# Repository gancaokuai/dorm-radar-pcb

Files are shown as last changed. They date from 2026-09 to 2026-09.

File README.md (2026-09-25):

# Dorm Radar PCB

ESP32-C3 based local motion-alert PCB project. The system uses an LD2450 radar on the transmitter board and a local LED on the receiver board. Communication uses ESP-NOW. No camera, microphone, cloud service, or charging circuit is included.

## Boards

- TX board: 70 mm x 42 mm, LD2450 interface and ESP-NOW transmitter
- RX board: 68 mm x 42 mm, ESP-NOW receiver and LED indicator

## Hardware

- ESP32-C3-WROOM-02
- LD2450 24 GHz radar module
- MT3608 5 V boost converter
- AP2112K-3.3 regulator
- External protected 1S 18650 battery pack
- Two-layer PCB with bottom ground plane

## Repository Layout

```text
hardware/kicad/DormRadar/
  DormRadar.kicad_pro
  DormRadar.kicad_sch
  generate_schematic.py
  generate_pcbs.py
  release/
    BOM_common.csv
    BOM_TX.csv
    BOM_RX.csv
    TX/
      DormRadar_TX.kicad_pcb
      DRC.txt
      gerber/
      drill/
      position/
    RX/
      DormRadar_RX.kicad_pcb
      DRC.txt
      gerber/
      drill/
      position/
```

## Firmware

The initial ESP32-C3 firmware MVP is in `firmware/`.

- TX reads the LD2450 radar and sends detection state over ESP-NOW.
- RX validates the packet and drives the local LED.
- The build script uses `F:\DormRadar` as an ASCII junction because the ESP32 GCC toolchain cannot resolve the Chinese project path.
- Build with `F:\防宿管雷达\firmware\build.ps1 all`.

See `firmware/README.md` for pin mapping, thresholds, and first-board bring-up steps.
## Verification

- TX: 0 unconnected pads, 0 electrical errors
- RX: 0 unconnected pads, 0 electrical errors
- Remaining DRC items are silkscreen-only warnings caused by the ESP32 antenna overhang and local reference text placement.
- Freerouting 2.4.1 was used in single-thread mode, then all tracks below 0.20 mm were normalized to at least 0.20 mm.

## Notes

Use this design only in compliance with local rules and do not modify fire, access-control, or safety equipment. The radar should have direct line of sight to the intended detection zone.

## Licensing

This is a multi-licensed project. Firmware is under Apache-2.0, hardware design files are under CERN-OHL-W-2.0, and documentation is under CC BY-SA 4.0. See LICENSING.md and LICENSES/ for details.

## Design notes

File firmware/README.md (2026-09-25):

# 防宿管雷达固件 v0.1

这是项目的初步程序部分，目标是先打通最小闭环：

```text
LD2450 -> TX ESP32-C3 -> ESP-NOW -> RX ESP32-C3 -> LED
```

当前版本不包含摄像头、麦克风、云端、充电和联网服务。

## 目录

```text
firmware/
  arduino/tx/tx.ino                 TX 固件
  arduino/rx/rx.ino                 RX 固件
  lib/DormRadarConfig/              引脚和判定参数
  lib/DormRadarProtocol/            ESP-NOW 数据包格式与 CRC
  lib/Ld2450/                       LD2450 UART 流式解析器
  test/native/                      可选的电脑端单元测试
  build.ps1                         使用已安装 Arduino CLI 编译
```

## 当前行为

TX 端：

- 以 256000 baud 读取 LD2450。
- 连续解析 30 字节 LD2450 数据帧，支持串口数据分片。
- 从最多 3 个目标中选择最近目标。
- 默认检测区域为雷达前方 `x = -700..700 mm`、`y = 100..2500 mm`。
- 目标进入区域后立即触发，离开后保持 1500 ms。
- LD2450 坐标使用符号幅值编码，距离由 x/y 计算。
- 每 500 ms 至少发送一次 ESP-NOW；状态变化时立即发送。

RX 端：

- 校验协议版本、包类型和 CRC-8。
- 收到有效警报时点亮 LED。
- 1.8 秒收不到心跳时，以短闪方式提示无线链路丢失。
- 无警报时 LED 熄灭。

## 硬件引脚

| 功能 | ESP32-C3 GPIO |
| --- | ---: |
| LD2450 RX，接雷达 TX | GPIO5 |
| LD2450 TX，接雷达 RX | GPIO4 |
| RX LED 控制 | GPIO7 |
| UART0 TX/RX | GPIO21 / GPIO20 |
| BOOT | GPIO9 |
| EN | EN |

LED 电路为 3.3 V -> 电阻 -> LED 阳极，LED 阴极接 GPIO7，因此固件按低电平点亮处理。

## 编译

需要 Arduino CLI 和 `esp32:esp32` 开发板包。本机已缓存 ESP32 Arduino Core 2.0.14。

```powershell
cd F:\防宿管雷达\firmware
.\build.ps1 all
```

也可以分别编译：

```powershell
.\build.ps1 tx
.\build.ps1 rx
```

输出位于：

```text
firmware\.build\tx\
firmware\.build\rx\
```

## 烧录

1. 将 J3 编程口接到 USB-TTL 串口模块。
2. 使用 Arduino IDE 打开对应的 `tx.ino` 或 `rx.ino`。
3. 开发板选择 `ESP32C3 Dev Module`。
4. UART 下载时需要 GPIO8 上拉到 3.3 V、GPIO9 拉低；否则芯片会进入 USB_BOOT 模式。
5. 两块板必须使用同一个 ESP-NOW 信道，当前固定为信道 1。

## 调参

引脚、区域、触发时间和无线信道都在：

```text
firmware/lib/DormRadarConfig/src/BoardConfig.h
```

首板联调建议：

1. 先只运行 RX，用串口确认其正常启动。
2. 单独运行 TX，确认 LD2450 帧率约为 10 帧/秒。
3. 用实际人体目标记录 x/y，再调整区域边界。
4. 穿过一面墙测试 ESP-NOW 丢包和唤醒延迟。
5. 确认 LED 亮灭逻辑后，再进入低功耗和外壳装配优化。

## 重要说明

当前 LD2450 解析按常见公开帧格式实现：

```text
AA FF 03 00 + 3 * 8 字节目标数据 + 55 CC
```

正式接线前应以手上 LD2450 模块的实际固件说明为准，并先确认波特率、帧头、坐标符号和距离字段。若模块使用不同固件版本，应只修改 `lib/Ld2450`，不要改动无线协议和 RX 端。

ESP-NOW 初版使用广播，不加密。不要将它用于门禁、消防、安防报警或其他安全关键系统。

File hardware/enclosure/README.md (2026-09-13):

# Radar Device Enclosures

SolidWorks 2024 editable enclosure models for the TX and RX boards.

## TX Enclosure

- Outer dimensions: 77 mm x 61 mm x 24 mm
- PCB: 70 mm x 42 mm
- Four M2.5 mounting positions
- ESP32-C3 antenna opening
- Openings for battery, LD2450 and programming connectors

## RX Enclosure

- Outer dimensions: 75 mm x 61 mm x 24 mm
- PCB: 68 mm x 42 mm
- Four M2.5 mounting positions
- ESP32-C3 antenna opening
- Battery/programming cable openings
- 4 mm LED window

## Printing

- Material: PETG, ABS or PLA
- Layer height: 0.20 mm
- Perimeters: 3 to 4
- Infill: 20 to 30 percent
- Print the base with its floor on the build plate
- Print the cover flat
- Use M2.5 x 8 mm self-tapping screws, four per enclosure

The ESP32 antenna area must remain free of metal. Use a non-metallic enclosure only.

## Print Files

Each device folder contains:

- Base STL
- Cover STL
- Combined print-plate STL with base and cover pre-arranged
- SolidWorks SLDPRT/SLDASM source
- STEP exchange files

All STL files were verified as closed manifold meshes. The print plate files are ready to import directly into a slicer.

## Fastening

Recommended removable assembly, per device:

- 4 x M2.5 x 22 mm cross-head self-tapping screws
- 4 x M2.5 x 15 mm nylon through-spacers
- 4 x M2.5 nylon washers
- 4 x self-adhesive rubber feet

Alternative tape assembly:

- 4 x M2.5 x 5 mm self-tapping screws for the PCB-to-boss mounting
- 3M VHB or equivalent double-sided tape for the cover

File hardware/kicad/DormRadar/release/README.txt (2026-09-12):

防宿管雷达 PCB 发布说明
日期: 2026-09-12
KiCad: 10.0.6

板卡:
- TX: 70 mm x 42 mm, 包含 LD2450 接口和 ESP-NOW 发射端
- RX: 68 mm x 42 mm, 仅包含 ESP-NOW 接收端和 LED

设计要点:
- ESP32-C3-WROOM-02 天线区悬出板边，减少 PCB 尺寸并保持天线净空
- 1S 18650 电池输入，无充电功能
- MT3608 升压到 5V
- AP2112K-3.3 给 ESP32 供电
- 双层板，底层 GND 铺铜
- Freerouting 2.4.1 自动布线，单线程模式
- 最终 DRC: 0 个未连接焊盘，0 个电气错误，剩余仅为丝印边缘提示

生产文件:
- TX/gerber, TX/drill, TX/position
- RX/gerber, RX/drill, RX/position
- BOM_common.csv
- TX/DormRadar_TX.kicad_pcb
- RX/DormRadar_RX.kicad_pcb

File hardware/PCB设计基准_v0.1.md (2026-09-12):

# 防宿管雷达 PCB 设计基准 v0.1

## 1. 已确定约束
- 发射端和接收端使用 ESP-NOW。
- 无线链路距离约 2m，需要穿过一面墙。
- 雷达探测不需要穿墙。
- 红外对射方案取消。
- 接收端只需要 LED 提示。
- PCB 不设计充电功能。
- 电池允许使用多节 18650。
- 目标最低连续工作时间 24h。

## 2. 推荐系统形态
检测端：
LD2450 雷达 + ESP32-C3-MINI-1 + 1S3P 18650 + 5V 升压 + 3.3V LDO

接收端：
ESP32-C3-MINI-1 + LED + 1S2P 18650 + 5V 升压 + 3.3V LDO

建议做一块通用 PCB，通过元件不安装和固件选择实现两种版本：
- TX 版本：安装 LD2450 接口。
- RX 版本：不安装 LD2450，安装 LED。

## 3. 初步电路模块
1. 1S 锂电池输入
   - XT30 或 JST-VH 接口
   - 2A 保险丝或自恢复保险丝
   - 反接保护 P-MOSFET
   - TVS 和输入滤波电容
   - 不设计充电、均衡和电量计
2. 5V 升压
   - MT3608 作为初版方案
   - 5V 输出给 LD2450 和 3.3V LDO
   - 峰值输出能力按 0.8A 以上设计
3. 3.3V 电源
   - AP2112K-3.3 或同等级 600mA LDO
   - 给 ESP32-C3-MINI-1、LED 和调试接口供电
4. 主控
   - ESP32-C3-MINI-1，独立模块
   - EN 复位 RC、BOOT 上拉、去耦电容
   - 预留 TX/RX/EN/BOOT/GND/3.3V 调试焊盘或排针
5. 雷达接口
   - LD2450 5V、GND、TX、RX
   - 先按 3.3V UART 设计，正式布线前核对雷达数据手册
   - 雷达建议通过短排线外接，避免载体板地平面影响 24GHz 天线
6. LED
   - ESP32 GPIO 串 1k 电阻驱动单颗 LED
   - 低亮度版本不需要 MOSFET

## 4. PCB 初步指标
- 层数：2 层
- 板材：FR-4，1.6mm
- 铜厚：1oz
- 暂定尺寸：55mm x 30mm，不含外接电池组
- 电池组通过连接器外接，PCB 上不焊 18650 电池座
- 四角预留 M2.5 安装孔
- 雷达和 ESP32 天线分别布置在板两端

## 5. 布局要求
- ESP32-C3-MINI-1 天线端放在板边，天线投影区禁止铺铜和放金属件。
- 电池、电感、升压电路和雷达尽量远离 ESP32 天线。
- MT3608 的输入电容、电感、二极管和输出电容形成最小回路。
- 5V 和电池走线按至少 1A 设计，关键电源走线加宽并多打过孔。
- LD2450 若直接上板，其天线前方和下方必须按厂家说明保留净空。
- 雷达模块建议通过 5-pin 1.27mm 排线外接，便于调角度和减少遮挡。
- 接收端天线保持竖直，避免紧贴电池和金属外壳。

## 6. 电源估算
按 3 节 3500mAh 18650 并联：
- 标称能量约 38.9Wh。
- 可用能量按 80% 估算约 31Wh。
- 检测端平均功耗按 0.6-0.8W 估算。
- 预计续航约 39-52h。

按接收端 2 节 3500mAh 18650 并联：
- 标称能量约 25.9Wh。
- ESP32 持续接收场景预计可工作 50h 以上。
- LED 只在触发时点亮，对续航影响很小。

## 7. 后续必须确认
- 是否接受外接 18650 电池组，还是要求电池座集成到 PCB。
- PCB 最大允许尺寸和外壳安装方式。
- LD2450 使用外接排线还是直接贴装在 PCB 上。
- 编程方式使用 6-pin 排针、焊盘，还是增加仅用于数据编程的 USB-C。
- 墙面材质和 ESP-NOW 实测链路余量。

## 8. 计划交付物
- KiCad 原理图工程
- KiCad PCB 工程
- Gerber 和钻孔文件
- BOM 和贴片坐标文件
- 装配图
- 3D STEP 模型
- 打样和首板测试说明

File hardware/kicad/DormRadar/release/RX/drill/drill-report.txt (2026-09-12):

Drill report for DormRadar_RX.kicad_pcb
Created on 2026-09-12T20:41:57

Copper Layer Stackup:
    =============================================================
    L1 :  F.Cu                      front
    L2 :  B.Cu                      back

Drill file 'DormRadar_RX-PTH.drl' contains
    plated through holes:
    =============================================================
    T1  0.200mm  0.0079"  (12 holes))
    T2  0.300mm  0.0118"  (13 holes))
    T3  1.000mm  0.0394"  (5 holes))
    T4  1.700mm  0.0669"  (2 holes))

    Total plated holes count 32

Drill file 'DormRadar_RX-NPTH.drl' contains
    unplated through holes:
    =============================================================
    T1  2.700mm  0.1063"  (4 holes))

    Total unplated holes count 4

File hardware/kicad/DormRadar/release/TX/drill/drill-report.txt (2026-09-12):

Drill report for DormRadar_TX.kicad_pcb
Created on 2026-09-12T20:41:55

Copper Layer Stackup:
    =============================================================
    L1 :  F.Cu                      front
    L2 :  B.Cu                      back

Drill file 'DormRadar_TX-PTH.drl' contains
    plated through holes:
    =============================================================
    T1  0.200mm  0.0079"  (12 holes))
    T2  0.300mm  0.0118"  (15 holes))
    T3  0.650mm  0.0256"  (5 holes))
    T4  1.000mm  0.0394"  (5 holes))
    T5  1.700mm  0.0669"  (2 holes))

    Total plated holes count 39

Drill file 'DormRadar_TX-NPTH.drl' contains
    unplated through holes:
    =============================================================
    T1  2.700mm  0.1063"  (4 holes))

    Total unplated holes count 4

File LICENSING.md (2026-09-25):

# Licensing

This repository contains multiple categories of works with different licenses.

## Firmware

The firmware source code under `firmware/` is licensed under the Apache License 2.0.

SPDX-License-Identifier: Apache-2.0

Full text: `LICENSES/Apache-2.0.txt`

## Hardware Design

The hardware design files under `hardware/`, including KiCad schematics, PCB layouts, BOM files, manufacturing outputs, mechanical design files, and enclosure files, are licensed under the CERN Open Hardware Licence Version 2 - Weakly Reciprocal.

SPDX-License-Identifier: CERN-OHL-W-2.0

Full text: `LICENSES/CERN-OHL-W-2.0.txt`

## Documentation

Project documentation and explanatory text, including `README.md`, `firmware/README.md`, and other documentation files, are licensed under the Creative Commons Attribution-ShareAlike 4.0 International License.

SPDX-License-Identifier: CC-BY-SA-4.0

Full text: `LICENSES/CC-BY-SA-4.0.txt`

## Third-Party Material

Third-party libraries, components, datasheets, trademarks, and referenced materials remain subject to their respective licenses and terms. If a file contains an explicit license notice or SPDX identifier, that notice takes precedence for that file.

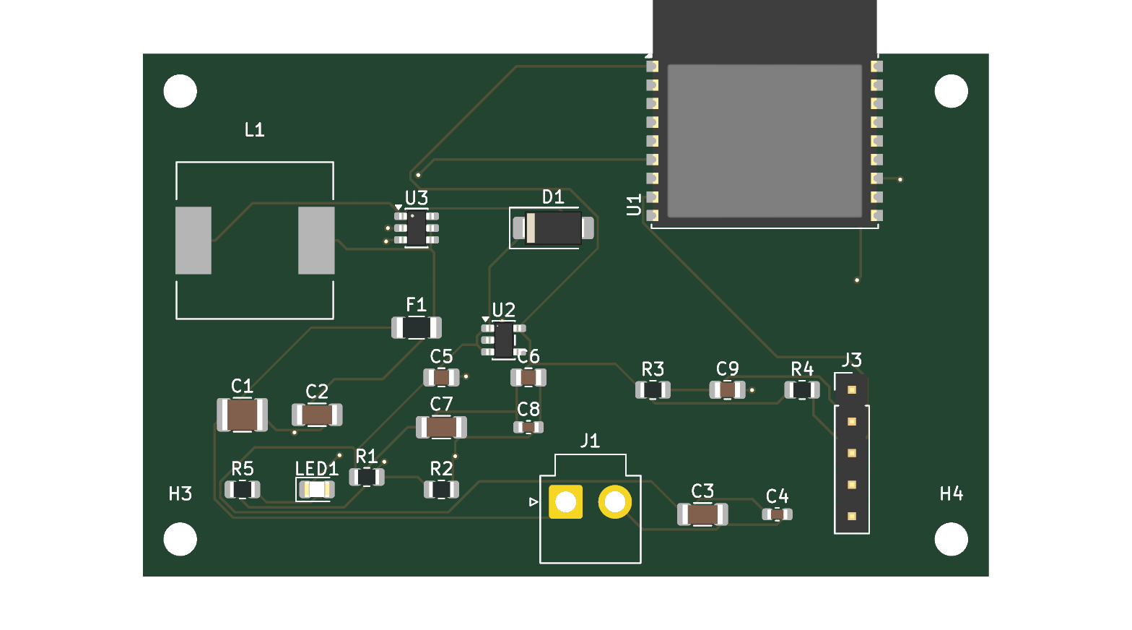
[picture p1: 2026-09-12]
hardware/kicad/DormRadar/release/RX/DormRadar_RX_final.png

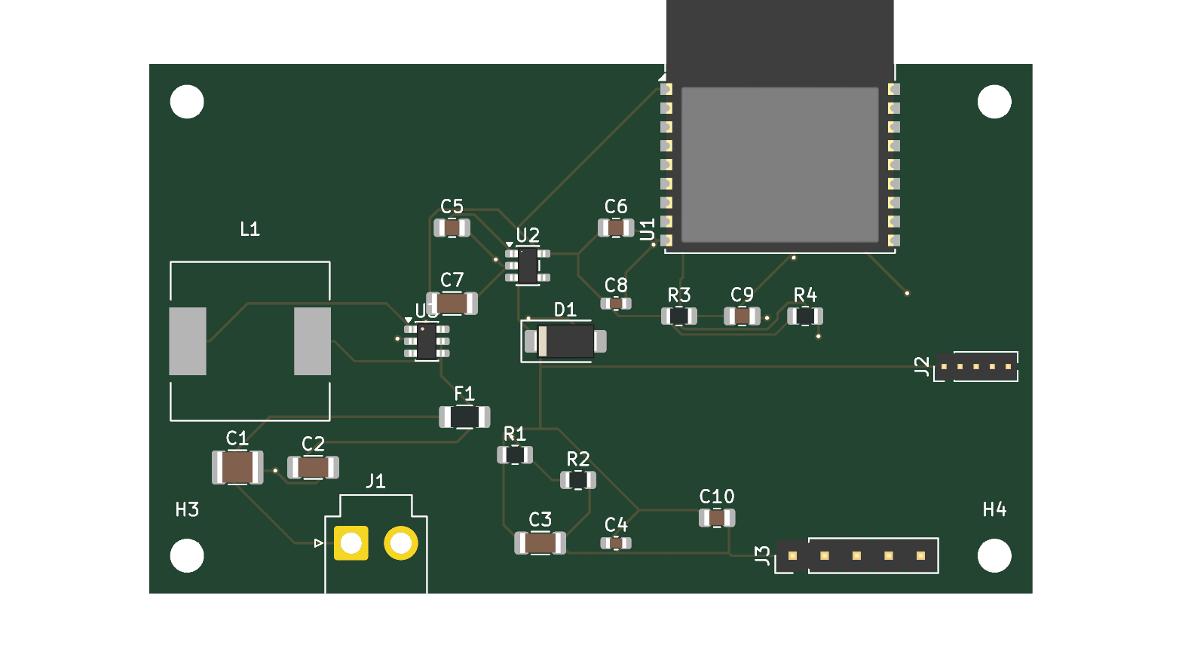
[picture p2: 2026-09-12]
hardware/kicad/DormRadar/release/TX/DormRadar_TX_final.png

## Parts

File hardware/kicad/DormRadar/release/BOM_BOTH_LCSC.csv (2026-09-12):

Comment | Designator | Footprint | Quantity | Supplier
100uF 10V X5R | TXC1,RXC1 | 1210 | 2 | C23742
22uF 25V X5R | TXC2,TXC3,RXC2,RXC3 | 1206 | 4 | C12891
0.1uF 50V X7R | TXC4,TXC8,RXC4,RXC8 | 0603 | 4 | C1591
1uF 50V X7R | TXC5,TXC6,TXC9,RXC5,RXC6,RXC9 | 0805 | 6 | C28323
22uF 6.3V X5R | TXC7,RXC7 | 1206 | 2 | C159759
10uF 25V X5R | TXC10 | 0805 | 1 | C15850
SS34 Schottky | TXD1,RXD1 | SMA | 2 | C8678
Fuse 2A 1206 | TXF1,RXF1 | 1206 | 2 | C3105
JST VH B2P-VH-B | TXJ1,RXJ1 | JST VH 2P 3.96mm | 2 | C265114
Header 1.27mm 1x5 | TXJ2 | 1.27mm 1x5 | 1 | C962329
Header 2.54mm 1x5 | TXJ3,RXJ3 | 2.54mm 1x5 | 2 | C492404
Inductor 22uH 3.6A | TXL1,RXL1 | 12.3x12.3mm | 2 | C9905
Resistor 73.2k 1% | TXR1,RXR1 | 0805 | 2 | C228988
Resistor 10k 1% | TXR2,TXR3,TXR4,RXR2,RXR3,RXR4 | 0805 | 6 | C84376
Resistor 470R 1% | RXR5 | 0805 | 1 | C114564
LED Red | RXLED1 | 0805 | 1 | C2295
ESP32-C3-WROOM-02-N4 | TXU1,RXU1 | SMD 20x18mm | 2 | C2934560
AP2112K-3.3TRG1 | TXU2,RXU2 | SOT-25-5 | 2 | C51118
MT3608 | TXU3,RXU3 | SOT-23-6 | 2 | C84817

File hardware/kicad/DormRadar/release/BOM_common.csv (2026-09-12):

Refs | Value | Footprint | Qty | DNP
C1 | 100uF/10V | Capacitor_SMD:C_1210_3225Metric | 1
C2 | 22uF/10V | Capacitor_SMD:C_1206_3216Metric | 1
C3 | 22uF/10V | Capacitor_SMD:C_1206_3216Metric | 1
C4 | 0.1uF | Capacitor_SMD:C_0603_1608Metric | 1
C5 | 1uF | Capacitor_SMD:C_0805_2012Metric | 1
C6 | 1uF | Capacitor_SMD:C_0805_2012Metric | 1
C7 | 22uF/6.3V | Capacitor_SMD:C_1206_3216Metric | 1
C8 | 0.1uF | Capacitor_SMD:C_0603_1608Metric | 1
C9 | 1uF | Capacitor_SMD:C_0805_2012Metric | 1
C10 | 10uF/10V | Capacitor_SMD:C_0805_2012Metric | 1
D1 | SS34 | Diode_SMD:D_SMA | 1
F1 | 2A | Fuse:Fuse_1206_3216Metric | 1
J1 | BAT_1S | Connector_JST:JST_VH_B2P-VH-B_1x02_P3.96mm_Vertical | 1
J2 | LD2450 | Connector_PinHeader_1.27mm:PinHeader_1x05_P1.27mm_Vertical | 1
J3 | PROG | Connector_PinHeader_2.54mm:PinHeader_1x05_P2.54mm_Vertical | 1
L1 | 22uH | Inductor_SMD:L_12x12mm_H4.5mm | 1
LED1 | RED | LED_SMD:LED_0805_2012Metric | 1
R1 | 73.2k | Resistor_SMD:R_0805_2012Metric | 1
R2 | 10k | Resistor_SMD:R_0805_2012Metric | 1
R3 | 10k | Resistor_SMD:R_0805_2012Metric | 1
R4 | 10k | Resistor_SMD:R_0805_2012Metric | 1
R5 | 470R | Resistor_SMD:R_0805_2012Metric | 1
U1 | ESP32-C3-WROOM-02 | RF_Module:ESP32-C3-WROOM-02 | 1
U2 | AP2112K-3.3 | Package_TO_SOT_SMD:SOT-23-5 | 1
U3 | MT3608 | Package_TO_SOT_SMD:SOT-23-6 | 1

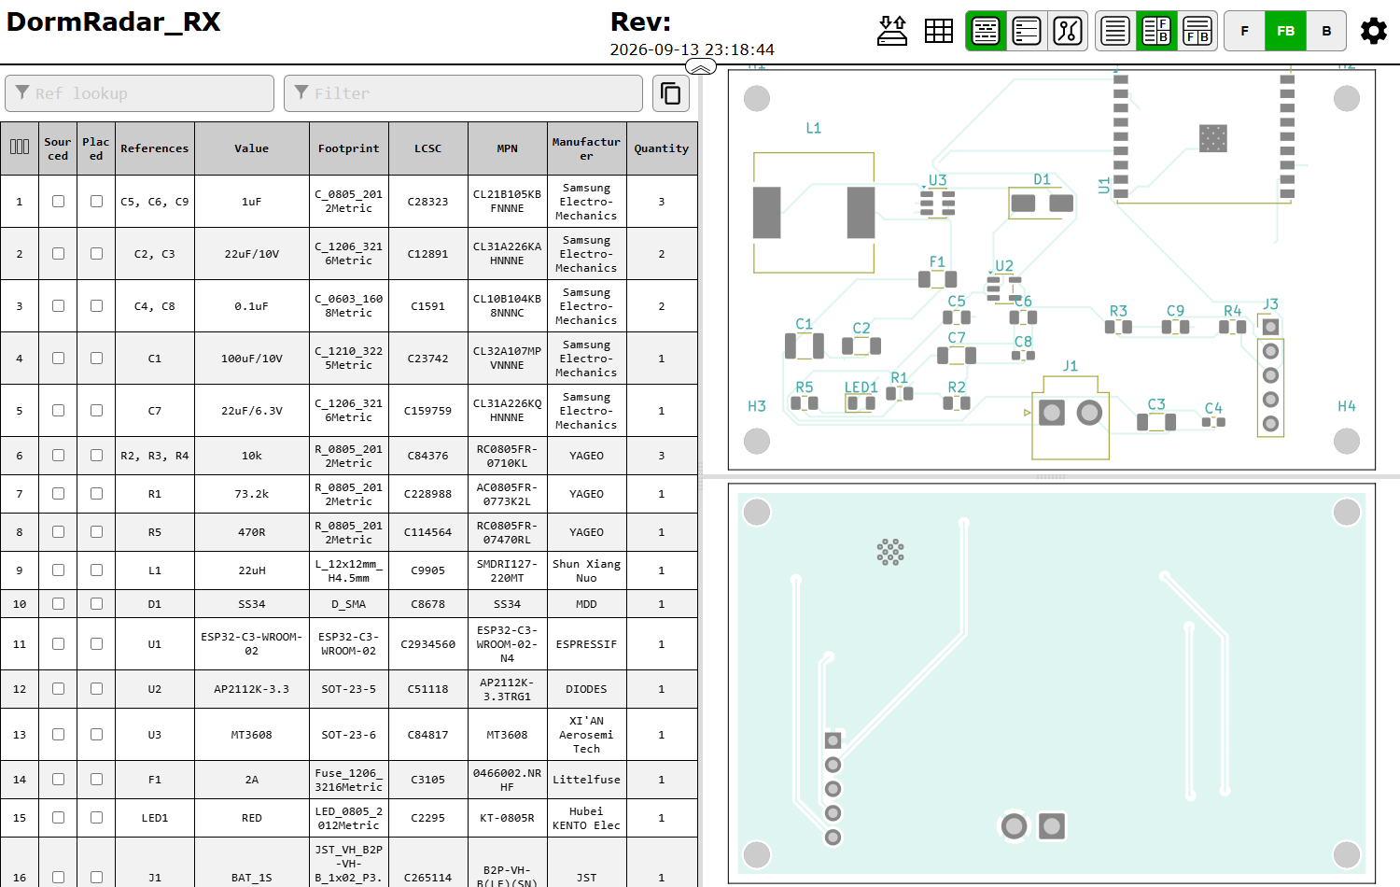
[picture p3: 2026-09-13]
hardware/kicad/DormRadar/release/RX/iBOM_RX_preview.png

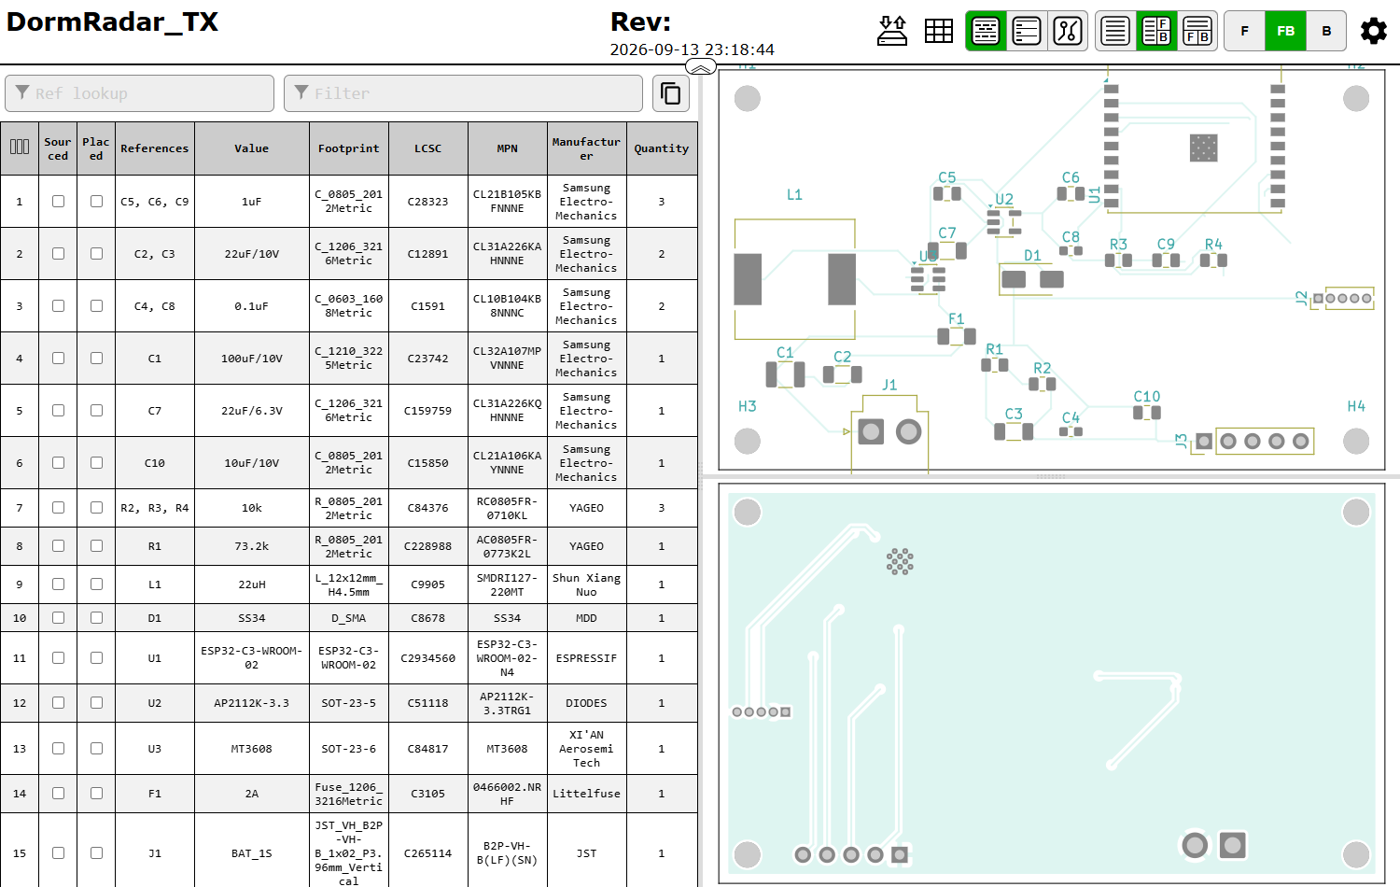
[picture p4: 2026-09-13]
hardware/kicad/DormRadar/release/TX/iBOM_TX_preview.png

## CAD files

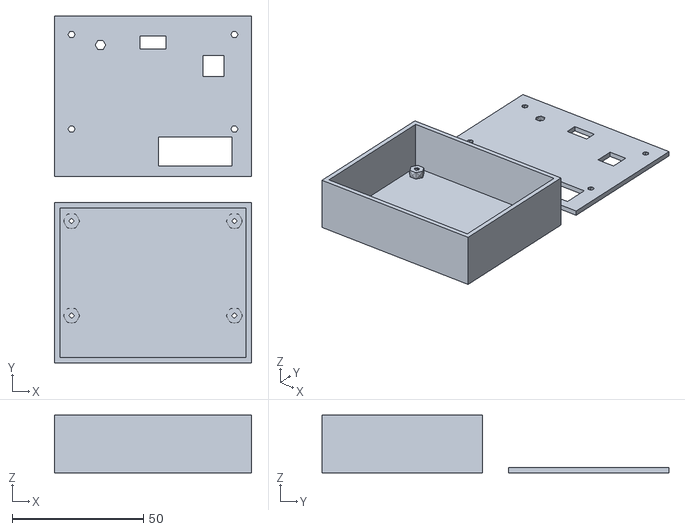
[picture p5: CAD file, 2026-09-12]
hardware/enclosure/RX/RX_PrintPlate.stl
75.0 x 132.0 x 22.0

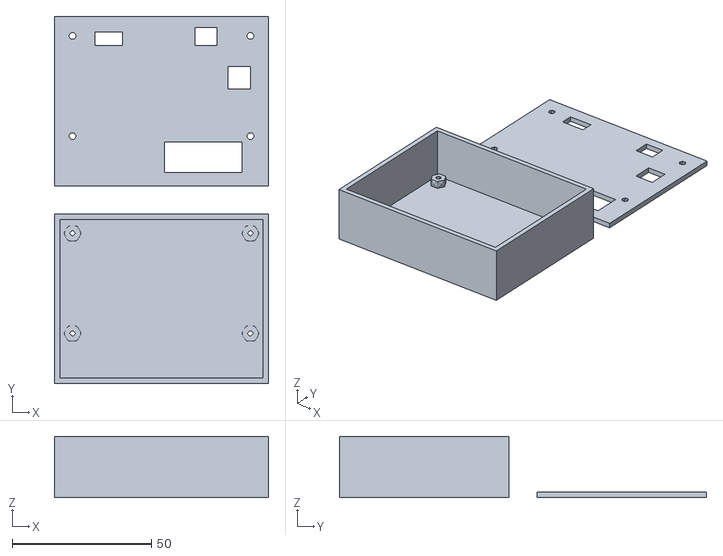
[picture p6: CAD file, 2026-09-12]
hardware/enclosure/TX/TX_PrintPlate.stl
77.0 x 132.0 x 22.0

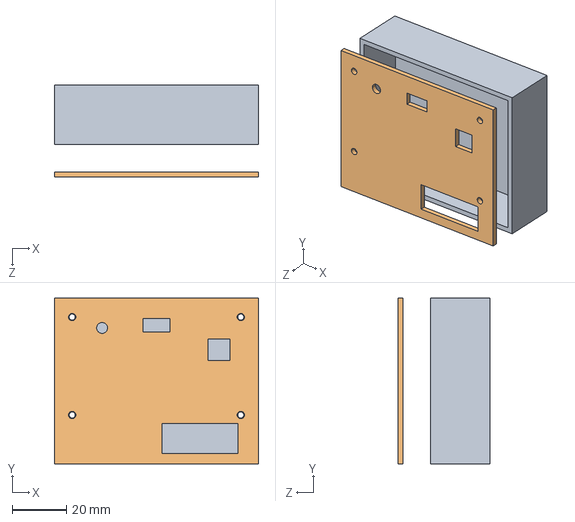
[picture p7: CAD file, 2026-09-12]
hardware/enclosure/RX/RX_Enclosure.STEP
75.0 x 61.0 x 34.0 mm
RX_Base
RX_Cover

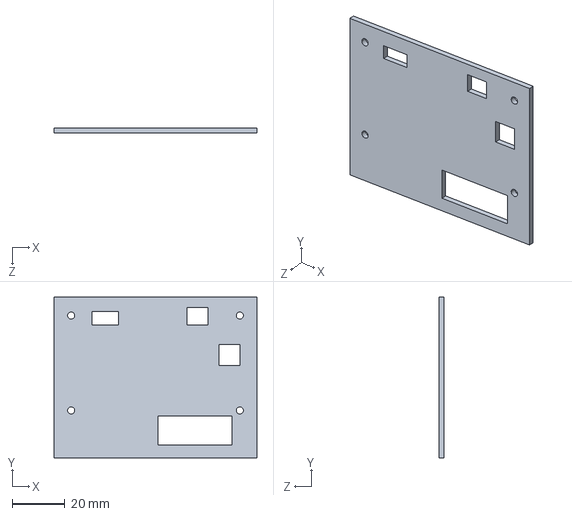
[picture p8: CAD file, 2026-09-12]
hardware/enclosure/TX/TX_Cover.STEP
77.0 x 61.0 x 2.00 mm

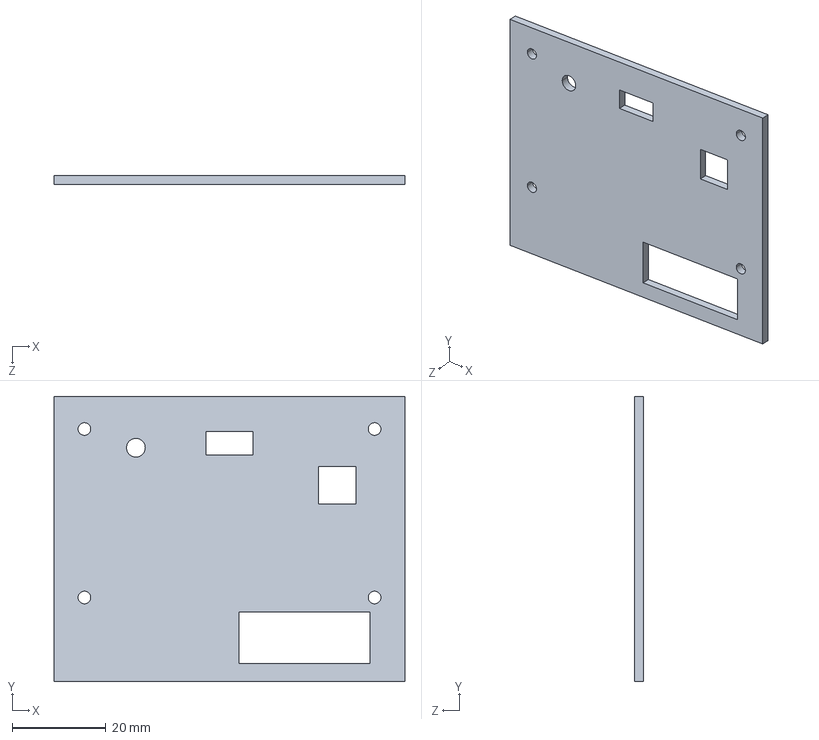
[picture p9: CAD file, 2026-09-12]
hardware/enclosure/RX/RX_Cover.STEP
75.0 x 61.0 x 2.00 mm

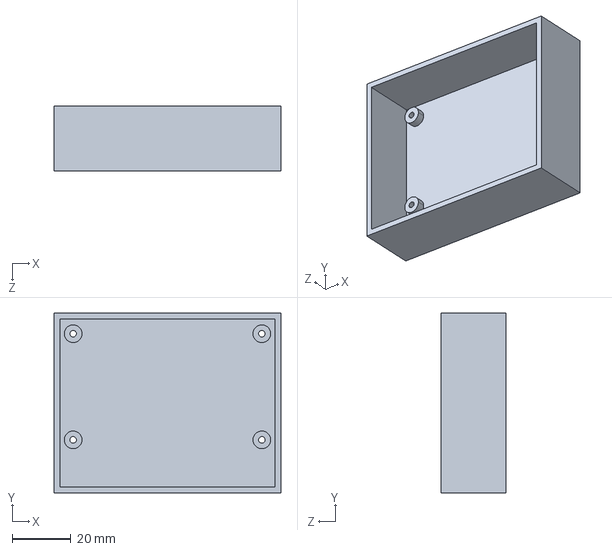
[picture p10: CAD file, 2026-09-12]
hardware/enclosure/TX/TX_Base.STEP
77.0 x 61.0 x 22.0 mm

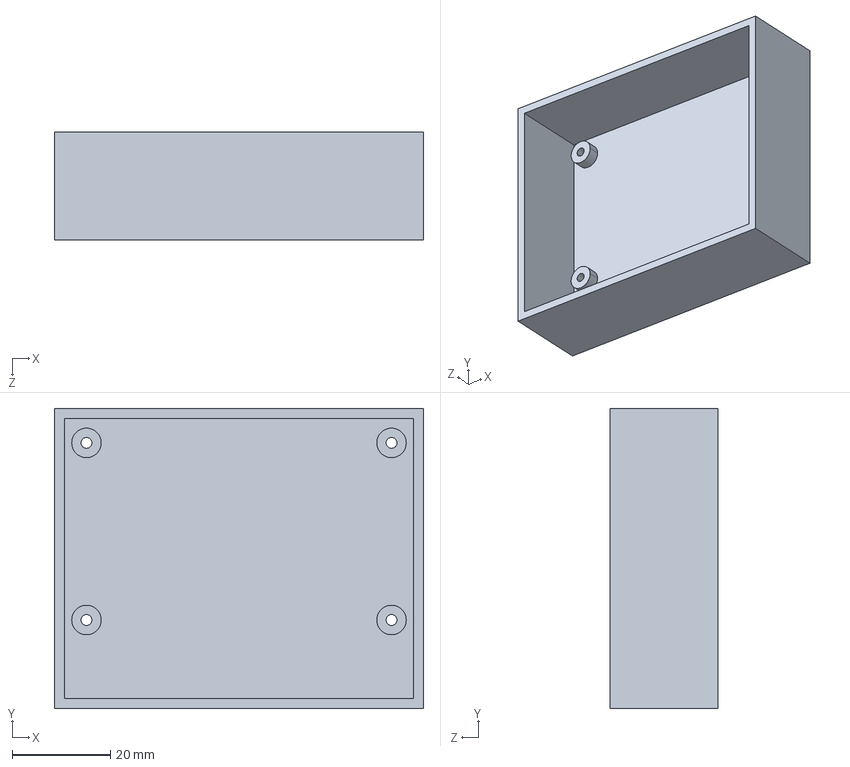
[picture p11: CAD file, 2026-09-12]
hardware/enclosure/RX/RX_Base.STEP
75.0 x 61.0 x 22.0 mm

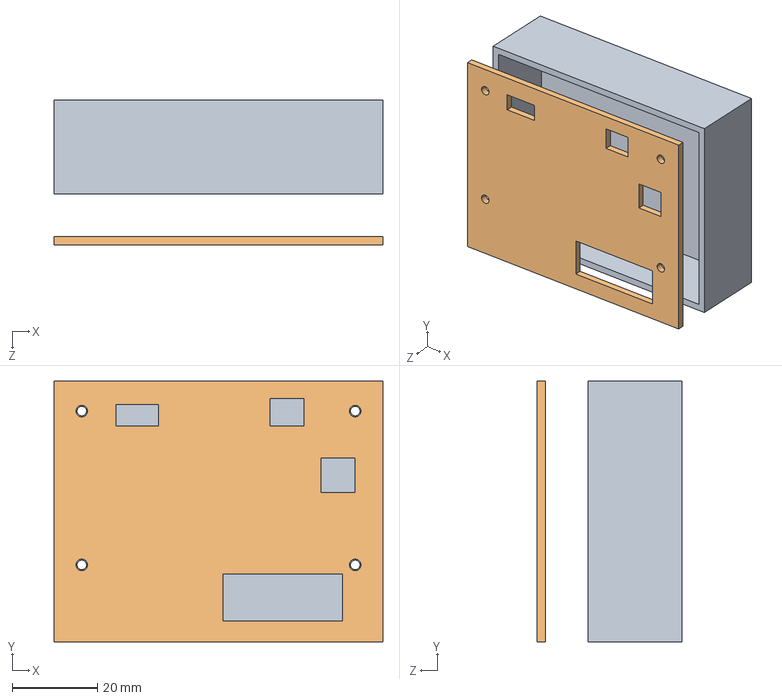
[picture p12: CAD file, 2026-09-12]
hardware/enclosure/TX/TX_Enclosure.STEP
77.0 x 61.0 x 34.0 mm
TX_Base
TX_Cover

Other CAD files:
hardware/enclosure/RX/RX_Base.SLDPRT
hardware/enclosure/RX/RX_Base.stl
hardware/enclosure/RX/RX_Cover.SLDPRT
hardware/enclosure/RX/RX_Cover.stl
hardware/enclosure/RX/RX_Enclosure.SLDASM
hardware/enclosure/TX/TX_Base.SLDPRT
hardware/enclosure/TX/TX_Base.stl
hardware/enclosure/TX/TX_Cover.SLDPRT
hardware/enclosure/TX/TX_Cover.stl
hardware/enclosure/TX/TX_Enclosure.SLDASM

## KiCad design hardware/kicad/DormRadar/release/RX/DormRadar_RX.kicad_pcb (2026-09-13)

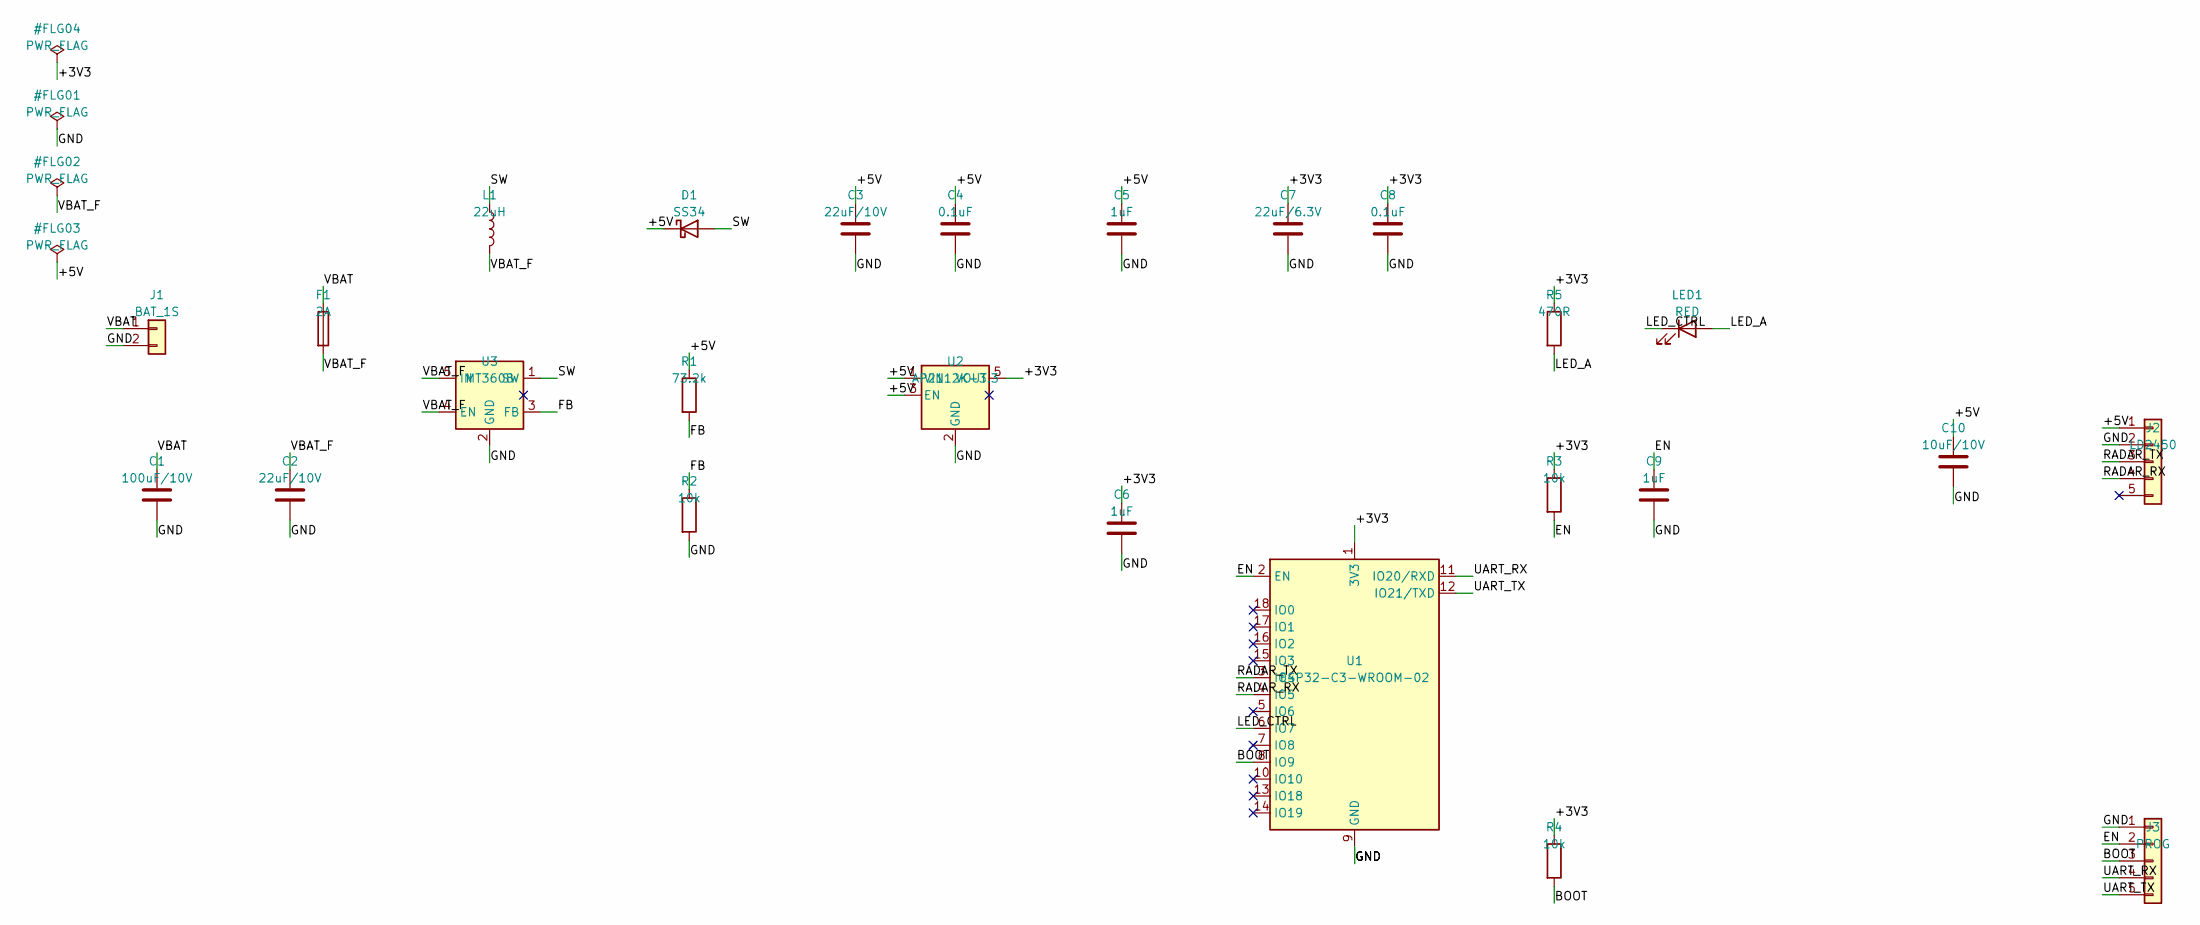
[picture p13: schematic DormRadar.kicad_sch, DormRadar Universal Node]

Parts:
C1: 100uF/10V; C_1210_3225Metric
C2, C3: 22uF/10V; C_1206_3216Metric
C4, C8: 0.1uF; C_0603_1608Metric
C5, C6, C9: 1uF; C_0805_2012Metric
C7: 22uF/6.3V; C_1206_3216Metric
C10: 10uF/10V; C_0805_2012Metric
D1: SS34; D_SMA
F1: 2A; Fuse_1206_3216Metric
J1: BAT_1S; JST_VH_B2P-VH-B_1x02_P3.96mm_Vertical
J2: LD2450; PinHeader_1x05_P1.27mm_Vertical
J3: PROG; PinHeader_1x05_P2.54mm_Vertical
L1: 22uH; L_12x12mm_H4.5mm
LED1: RED; LED_0805_2012Metric
R1: 73.2k; R_0805_2012Metric
R2, R3, R4: 10k; R_0805_2012Metric
R5: 470R; R_0805_2012Metric
U1: ESP32-C3-WROOM-02
U2: AP2112K-3.3; SOT-23-5
U3: MT3608; SOT-23-6

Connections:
+3V3: C6.1, C7.1, C8.1, R3.1, R4.1, R5.1, U1.1 (3V3), U2.5
+5V: C3.1, C4.1, C5.1, C10.1, D1.1 (K), J2.1, R1.1, U2.1, U2.3
BOOT: J3.3, R4.2, U1.8 (IO9)
EN: C9.1, J3.2, R3.2, U1.2 (EN)
FB: R1.2, R2.1, U3.3 (FB)
GND: C1.2, C2.2, C3.2, C4.2, C5.2, C6.2, C7.2, C8.2, C9.2, C10.2, J1.2, J2.2, J3.1, R2.2, U1.9 (GND), U1.19 (GND), U2.2, U3.2 (GND)
LED_A: LED1.2 (A), R5.2
LED_CTRL: LED1.1 (K), U1.6 (IO7)
RADAR_RX: J2.4, U1.4 (IO5)
RADAR_TX: J2.3, U1.3 (IO4)
SW: D1.2 (A), L1.1, U3.1 (SW)
UART_RX: J3.4, U1.11 (IO20/RXD)
UART_TX: J3.5, U1.12 (IO21/TXD)
VBAT: C1.1, F1.1, J1.1
VBAT_F: C2.1, F1.2, L1.2, U3.4 (EN), U3.5 (IN)

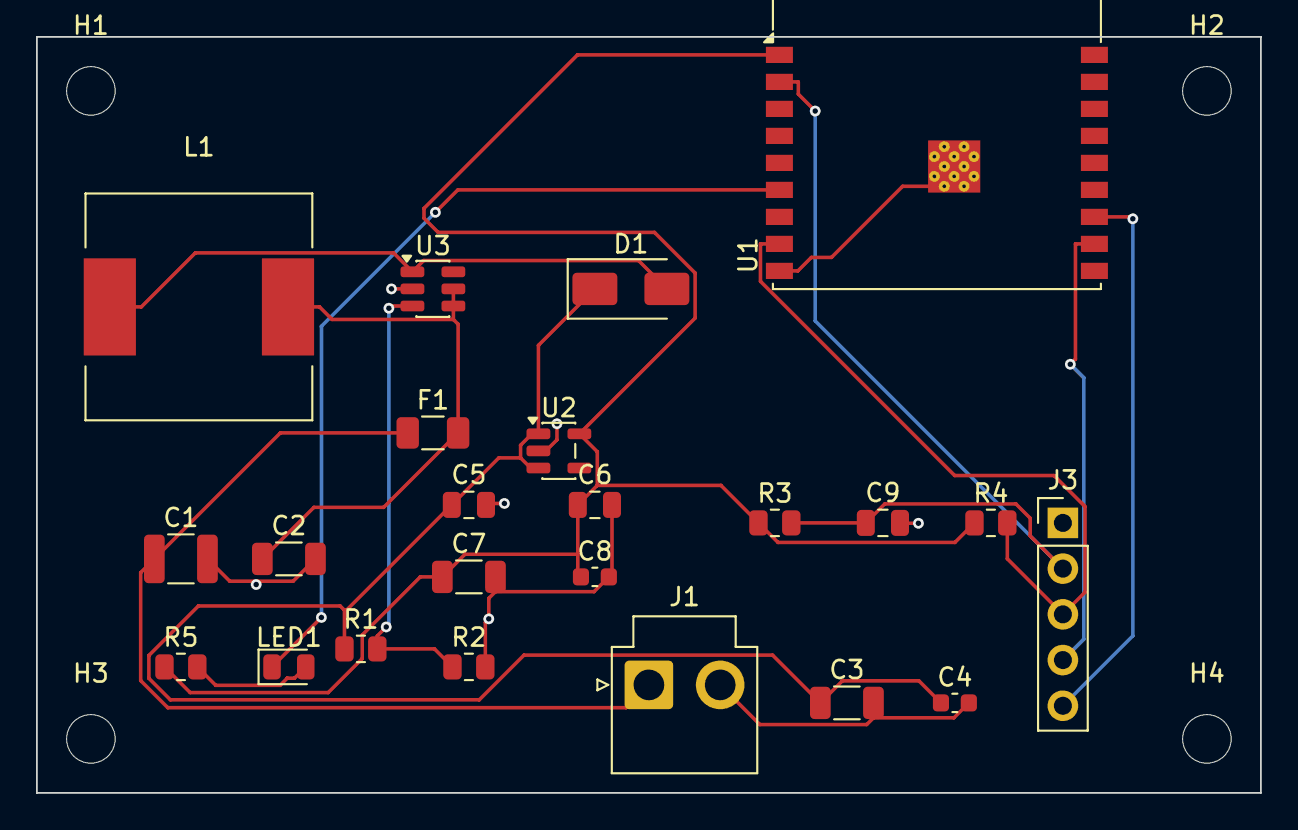
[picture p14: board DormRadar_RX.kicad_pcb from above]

Board: 2 copper layers, 68.0 x 42.0 mm, 27 parts (0 on the bottom side), 13 nets.

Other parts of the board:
H1, H2, H3, H4: M2.5; MountingHole_2.7mm_M2.5

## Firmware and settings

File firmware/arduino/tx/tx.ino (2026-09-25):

#include <Arduino.h>
#include "F:/DormRadar/firmware/lib/DormRadarConfig/src/BoardConfig.h"
#include "F:/DormRadar/firmware/lib/DormRadarProtocol/src/DormRadarProtocol.h"
#include "F:/DormRadar/firmware/lib/Ld2450/src/Ld2450.h"
#include <WiFi.h>
#include <esp_now.h>
#include <esp_wifi.h>

namespace cfg = dorm_radar::config;
using dorm_radar::DetectionPacket;
using dorm_radar::Ld2450Parser;
using dorm_radar::RadarFrame;
using dorm_radar::RadarTarget;

namespace {

HardwareSerial RadarSerial(1);
Ld2450Parser radarParser;
RadarFrame latestFrame;
bool hasRadarFrame = false;
uint32_t lastRadarFrameMs = 0;
uint16_t packetSequence = 0;
uint32_t lastTelemetryMs = 0;
uint32_t lastDebugMs = 0;
bool espNowReady = false;

bool zoneCandidate = false;
uint32_t zoneCandidateSinceMs = 0;
uint32_t lastZoneSeenMs = 0;
bool alertActive = false;
uint32_t alertSinceMs = 0;

struct TargetSelection {
    bool anyTarget;
    bool anyInZone;
    uint8_t activeTargetCount;
    RadarTarget closest;
    RadarTarget closestInZone;
};

int32_t abs32(int32_t value) {
    return value < 0 ? -value : value;
}

bool saneTarget(const RadarTarget& target, uint16_t* distance) {
    if (!target.valid) {
        return false;
    }

    if (abs32(target.x_mm) > cfg::kCoordinateLimitMm ||
        abs32(target.y_mm) > cfg::kCoordinateLimitMm) {
        return false;
    }

    if (distance != NULL) {
        *distance = target.distance_mm;
    }
    return true;
}

bool targetInZone(const RadarTarget& target) {
    return target.valid &&
           target.x_mm >= cfg::kZoneMinXmm &&
           target.x_mm <= cfg::kZoneMaxXmm &&
           target.y_mm >= cfg::kZoneMinYmm &&
           target.y_mm <= cfg::kZoneMaxYmm &&
           target.distance_mm >= cfg::kZoneMinDistanceMm &&
           target.distance_mm <= cfg::kZoneMaxDistanceMm;
}

TargetSelection selectTargets(const RadarFrame& frame) {
    TargetSelection selection;
    memset(&selection, 0, sizeof(selection));

    uint16_t closestDistance = 0xFFFF;
    uint16_t closestZoneDistance = 0xFFFF;

    for (uint8_t i = 0; i < dorm_radar::kLd2450TargetCount; ++i) {
        uint16_t distance = 0;
        const RadarTarget& target = frame.targets[i];
        if (!saneTarget(target, &distance)) {
            continue;
        }

        ++selection.activeTargetCount;
        selection.anyTarget = true;

        if (distance < closestDistance) {
            closestDistance = distance;
            selection.closest = target;
        }

        if (targetInZone(target)) {
            selection.anyInZone = true;
            if (distance < closestZoneDistance) {
                closestZoneDistance = distance;
                selection.closestInZone = target;
            }
        }
    }

    return selection;
}

void updateAlert(uint32_t nowMs, const TargetSelection& selection,
                 bool radarHealthy) {
    if (!radarHealthy) {
        zoneCandidate = false;
        alertActive = false;
        alertSinceMs = 0;
        return;
    }

    if (selection.anyInZone) {
        lastZoneSeenMs = nowMs;
        if (!zoneCandidate) {
            zoneCandidate = true;
            zoneCandidateSinceMs = nowMs;
        }

        if (!alertActive &&
            nowMs - zoneCandidateSinceMs >= cfg::kTriggerDelayMs) {
            alertActive = true;
            alertSinceMs = nowMs;
        }
        return;
    }

    zoneCandidate = false;
    if (alertActive && nowMs - lastZoneSeenMs > cfg::kAlertHoldMs) {
        alertActive = false;
        alertSinceMs = 0;
    }
}

DetectionPacket makePacket(uint32_t nowMs, const TargetSelection& selection,
                           bool radarHealthy) {
    DetectionPacket packet;
    memset(&packet, 0, sizeof(packet));

    packet.sequence = packetSequence++;
    packet.uptime_ms = nowMs;
    packet.radar_frame_age_ms =
        hasRadarFrame ? nowMs - lastRadarFrameMs : 0xFFFFFFFFUL;
    packet.alert_ms = alertActive ? nowMs - alertSinceMs : 0;
    packet.target_count = selection.activeTargetCount;

    const RadarTarget& reported =
        selection.closestInZone.valid ? selection.closestInZone
                                      : selection.closest;
    packet.x_mm = reported.valid ? reported.x_mm : 0;
    packet.y_mm = reported.valid ? reported.y_mm : 0;
    packet.speed_cm_s = reported.valid ? reported.speed_cm_s : 0;
    packet.distance_mm = reported.valid ? reported.distance_mm : 0;

    if (selection.anyTarget) {
        packet.flags |= dorm_radar::kFlagTargetPresent;
    }
    if (selection.anyInZone) {
        packet.flags |= dorm_radar::kFlagTargetInZone;
    }
    if (alertActive) {
        packet.flags |= dorm_radar::kFlagAlert;
    }
    if (radarHealthy) {
        packet.flags |= dorm_radar::kFlagRadarHealthy;
    }

    dorm_radar::finalizeDetectionPacket(&packet);
    return packet;
}

void sendPacket(const DetectionPacket& packet) {
    if (!espNowReady) {
        return;
    }

    const uint8_t broadcastAddress[6] = {0xFF, 0xFF, 0xFF, 0xFF, 0xFF, 0xFF};
    esp_now_send(broadcastAddress,
                 reinterpret_cast<const uint8_t*>(&packet),
                 sizeof(packet));
}

bool initEspNow() {
    WiFi.mode(WIFI_STA);
    WiFi.disconnect();
    WiFi.setSleep(false);

    if (esp_wifi_set_ps(WIFI_PS_NONE) != ESP_OK) {
        return false;
    }
    if (esp_wifi_set_channel(cfg::kEspNowChannel,
                             WIFI_SECOND_CHAN_NONE) != ESP_OK) {
        return false;
    }
    if (esp_now_init() != ESP_OK) {
        return false;
    }

    esp_now_peer_info_t peer;
    memset(&peer, 0, sizeof(peer));
    const uint8_t broadcastAddress[6] = {0xFF, 0xFF, 0xFF, 0xFF, 0xFF, 0xFF};
    memcpy(peer.peer_addr, broadcastAddress, sizeof(broadcastAddress));
    peer.channel = cfg::kEspNowChannel;
    peer.ifidx = WIFI_IF_STA;
    peer.encrypt = false;

    return esp_now_add_peer(&peer) == ESP_OK;
}

void processRadar(uint32_t nowMs) {
    while (RadarSerial.available() > 0) {
        const uint8_t byte = static_cast<uint8_t>(RadarSerial.read());
        RadarFrame frame;
        if (radarParser.feed(byte, nowMs, &frame)) {
            latestFrame = frame;
            hasRadarFrame = true;
            lastRadarFrameMs = nowMs;
        }
    }
}

void printStatus(uint32_t nowMs, const TargetSelection& selection,
                 bool radarHealthy) {
    if (nowMs - lastDebugMs < 2000) {
        return;
    }
    lastDebugMs = nowMs;

    Serial.printf(
        "[TX] link=%s radar=%s targets=%u zone=%u alert=%u x=%d y=%d d=%u\n",
        espNowReady ? "ready" : "fail",
        radarHealthy ? "ok" : "stale",
        selection.activeTargetCount,
        selection.anyInZone ? 1 : 0,
        alertActive ? 1 : 0,
        selection.closest.valid ? selection.closest.x_mm : 0,
        selection.closest.valid ? selection.closest.y_mm : 0,
        selection.closest.valid ? selection.closest.distance_mm : 0);
}

}  // namespace

void setup() {
    Serial.begin(cfg::kSerialBaud);
    delay(100);

    RadarSerial.begin(cfg::kRadarBaud, SERIAL_8N1, cfg::kRadarRxPin,
                      cfg::kRadarTxPin);

    espNowReady = initEspNow();
    Serial.printf("[TX] boot, esp-now=%s, channel=%u, radar=%u baud\n",
                  espNowReady ? "ok" : "failed", cfg::kEspNowChannel,
                  cfg::kRadarBaud);
}

void loop() {
    const uint32_t nowMs = millis();
    processRadar(nowMs);

    const bool radarHealthy =
        hasRadarFrame && nowMs - lastRadarFrameMs <= cfg::kRadarTimeoutMs;
    const TargetSelection selection = selectTargets(latestFrame);
    updateAlert(nowMs, selection, radarHealthy);

    static bool lastAlertState = false;
    const bool stateChanged = alertActive != lastAlertState;
    if (stateChanged || nowMs - lastTelemetryMs >= cfg::kTelemetryPeriodMs) {
        const DetectionPacket packet =
            makePacket(nowMs, selection, radarHealthy);
        sendPacket(packet);
        lastTelemetryMs = nowMs;
        lastAlertState = alertActive;
    }

    printStatus(nowMs, selection, radarHealthy);
    delay(1);
}

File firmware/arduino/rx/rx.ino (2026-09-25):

#include <Arduino.h>
#include "F:/DormRadar/firmware/lib/DormRadarConfig/src/BoardConfig.h"
#include "F:/DormRadar/firmware/lib/DormRadarProtocol/src/DormRadarProtocol.h"
#include <WiFi.h>
#include <esp_now.h>
#include <esp_wifi.h>
#include <freertos/FreeRTOS.h>
#include <freertos/queue.h>

namespace cfg = dorm_radar::config;
using dorm_radar::DetectionPacket;

namespace {

QueueHandle_t packetQueue = NULL;
DetectionPacket lastPacket;
bool hasPacket = false;
uint32_t lastPacketMs = 0;
uint32_t lastDebugMs = 0;
volatile uint32_t validPackets = 0;
volatile uint32_t rejectedPackets = 0;
volatile uint32_t droppedPackets = 0;
bool espNowReady = false;

void writeLed(bool on) {
    const uint8_t level =
        cfg::kLedActiveHigh ? (on ? HIGH : LOW) : (on ? LOW : HIGH);
    digitalWrite(cfg::kStatusLedPin, level);
}

#if defined(ESP_ARDUINO_VERSION_MAJOR) && ESP_ARDUINO_VERSION_MAJOR >= 3
void onEspNowRecv(const esp_now_recv_info_t* info, const uint8_t* data,
                  int length) {
    (void)info;
#else
void onEspNowRecv(const uint8_t* macAddress, const uint8_t* data,
                  int length) {
    (void)macAddress;
#endif
    if (!dorm_radar::validateDetectionPacket(data,
                                             static_cast<size_t>(length))) {
        ++rejectedPackets;
        return;
    }

    DetectionPacket packet;
    memcpy(&packet, data, sizeof(packet));
    if (xQueueSend(packetQueue, &packet, 0) != pdTRUE) {
        ++droppedPackets;
        return;
    }
    ++validPackets;
}

bool initEspNow() {
    WiFi.mode(WIFI_STA);
    WiFi.disconnect();
    WiFi.setSleep(false);

    if (esp_wifi_set_ps(WIFI_PS_NONE) != ESP_OK) {
        return false;
    }
    if (esp_wifi_set_channel(cfg::kEspNowChannel,
                             WIFI_SECOND_CHAN_NONE) != ESP_OK) {
        return false;
    }
    if (esp_now_init() != ESP_OK) {
        return false;
    }

    esp_now_peer_info_t peer;
    memset(&peer, 0, sizeof(peer));
    const uint8_t broadcastAddress[6] = {0xFF, 0xFF, 0xFF, 0xFF, 0xFF, 0xFF};
    memcpy(peer.peer_addr, broadcastAddress, sizeof(broadcastAddress));
    peer.channel = cfg::kEspNowChannel;
    peer.ifidx = WIFI_IF_STA;
    peer.encrypt = false;

    if (esp_now_add_peer(&peer) != ESP_OK) {
        return false;
    }
    return esp_now_register_recv_cb(onEspNowRecv) == ESP_OK;
}

void processQueue(uint32_t nowMs) {
    DetectionPacket packet;
    while (packetQueue != NULL &&
           xQueueReceive(packetQueue, &packet, 0) == pdTRUE) {
        lastPacket = packet;
        lastPacketMs = nowMs;
        hasPacket = true;
    }
}

void updateLed(uint32_t nowMs) {
    const bool linkHealthy =
        hasPacket && nowMs - lastPacketMs <= cfg::kLinkTimeoutMs;

    if (!linkHealthy) {
        writeLed((nowMs % 1000) < 100);
        return;
    }

    const bool alert =
        (lastPacket.flags & dorm_radar::kFlagAlert) != 0;
    writeLed(alert);
}

void printStatus(uint32_t nowMs) {
    if (nowMs - lastDebugMs < 2000) {
        return;
    }
    lastDebugMs = nowMs;

    const bool linkHealthy =
        hasPacket && nowMs - lastPacketMs <= cfg::kLinkTimeoutMs;
    const bool alert =
        linkHealthy && (lastPacket.flags & dorm_radar::kFlagAlert) != 0;

    Serial.printf(
        "[RX] link=%s rssi=local valid=%u rejected=%u dropped=%u seq=%u "
        "alert=%u radar=%u age=%u x=%d y=%d d=%u\n",
        linkHealthy ? "ok" : "lost",
        static_cast<unsigned>(validPackets),
        static_cast<unsigned>(rejectedPackets),
        static_cast<unsigned>(droppedPackets),
        static_cast<unsigned>(lastPacket.sequence),
        alert ? 1 : 0,
        (lastPacket.flags & dorm_radar::kFlagRadarHealthy) ? 1 : 0,
        static_cast<unsigned>(lastPacket.radar_frame_age_ms),
        lastPacket.x_mm,
        lastPacket.y_mm,
        lastPacket.distance_mm);
}

}  // namespace

void setup() {
    Serial.begin(cfg::kSerialBaud);
    delay(100);

    digitalWrite(cfg::kStatusLedPin, HIGH);
    pinMode(cfg::kStatusLedPin, OUTPUT);
    writeLed(false);

    packetQueue = xQueueCreate(8, sizeof(DetectionPacket));
    espNowReady = packetQueue != NULL && initEspNow();

    Serial.printf("[RX] boot, esp-now=%s, channel=%u, queue=%s\n",
                  espNowReady ? "ok" : "failed", cfg::kEspNowChannel,
                  packetQueue != NULL ? "ok" : "failed");
}

void loop() {
    const uint32_t nowMs = millis();
    processQueue(nowMs);
    updateLed(nowMs);
    printStatus(nowMs);
    delay(1);
}

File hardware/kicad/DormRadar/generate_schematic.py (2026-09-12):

from pathlib import Path
import re
import uuid

SYM_DIR = Path(r"D:\Program Files\KiCad\10.0\share\kicad\symbols")
OUT = Path(r"F:\防宿管雷达\hardware\kicad\DormRadar\DormRadar.kicad_sch")
ROOT_UUID = str(uuid.uuid4())
PROJECT = "DormRadar"

def uid():
    return str(uuid.uuid4())

def balanced_block(text, start):
    depth = 0
    in_string = False
    escaped = False
    for i in range(start, len(text)):
        ch = text[i]
        if in_string:
            if escaped:
                escaped = False
            elif ch == '\\':
                escaped = True
            elif ch == '"':
                in_string = False
            continue
        if ch == '"':
            in_string = True
        elif ch == '(':
            depth += 1
        elif ch == ')':
            depth -= 1
            if depth == 0:
                return text[start:i+1]
    raise ValueError("Unbalanced block")

def load_symbol(lib, name):
    path = SYM_DIR / f"{lib}.kicad_sym"
    text = path.read_text(encoding="utf-8")
    start = text.find(f'(symbol "{name}"')
    if start < 0:
        raise ValueError(f"Symbol not found: {lib}:{name}")
    return balanced_block(text, start)

def get_extends(block):
    m = re.search(r'\(extends\s+"([^"]*)"\)', block)
    return m.group(1) if m else None

def symbol_pins(block):
    pins = []
    pattern = re.compile(r'\(pin\s+(?:input|output|bidirectional|passive|power_in|power_out|free|unspecified|no_connect)\s+')
    for m in pattern.finditer(block):
        pin_block = balanced_block(block, m.start())
        at = re.search(r'\(at\s+([-0-9.]+)\s+([-0-9.]+)\s+([-0-9.]+)\)', pin_block)
        name = re.search(r'\(name\s+"([^"]*)"', pin_block)
        number = re.search(r'\(number\s+"([^"]*)"', pin_block)
        if at and name and number:
            pins.append({"x": float(at.group(1)), "y": float(at.group(2)), "angle": float(at.group(3)), "name": name.group(1), "number": number.group(1)})
    return pins

def indented(block, levels=2):
    prefix = "\t" * levels
    return "\n".join(prefix + line for line in block.splitlines())

def fmt(v):
    if abs(v - round(v)) < 1e-9:
        return str(int(round(v)))
    return f"{v:.4f}".rstrip("0").rstrip(".")

def wire(a, b):
    return ("\t(wire\n\t\t(pts\n" f"\t\t\t(xy {fmt(a[0])} {fmt(a[1])}) (xy {fmt(b[0])} {fmt(b[1])})\n" "\t\t)\n\t\t(stroke\n\t\t\t(width 0)\n\t\t\t(type default)\n\t\t)\n" f"\t\t(uuid \"{uid()}\")\n\t)\n")

def label(name, pos):
    return (f'\t(label "{name}"\n' f"\t\t(at {fmt(pos[0])} {fmt(pos[1])} 0)\n" "\t\t(effects\n\t\t\t(font\n\t\t\t\t(size 1.27 1.27)\n\t\t\t)\n\t\t\t(justify left bottom)\n\t\t)\n" f"\t\t(uuid \"{uid()}\")\n\t)\n")

def no_connect(pos):
    return ("\t(no_connect\n" f"\t\t(at {fmt(pos[0])} {fmt(pos[1])})\n" f"\t\t(uuid \"{uid()}\")\n\t)\n")

def prop(name, value, pos, hide=False):
    h = "\n\t\t\t(hide yes)" if hide else ""
    return (f'\t\t(property "{name}" "{value}"\n' f"\t\t\t(at {fmt(pos[0])} {fmt(pos[1])} 0)\n" "\t\t\t(effects\n\t\t\t\t(font\n\t\t\t\t\t(size 1.27 1.27)\n\t\t\t\t)" + h + "\n\t\t\t)\n\t\t)\n")

def instance(comp):
    out = []
    out.append("\t(symbol\n")
    out.append(f'\t\t(lib_id "{comp["lib"]}:{comp["symbol"]}")\n')
    out.append(f'\t\t(at {fmt(comp["at"][0])} {fmt(comp["at"][1])} 0)\n')
    out.append("\t\t(unit 1)\n\t\t(exclude_from_sim no)\n\t\t(in_bom yes)\n\t\t(on_board yes)\n\t\t(dnp no)\n\t\t(fields_autoplaced yes)\n")
    out.append(f'\t\t(uuid "{uid()}")\n')
    ox, oy = comp["at"]
    out.append(prop("Reference", comp["ref"], (ox, oy - 5.08)))
    out.append(prop("Value", comp["value"], (ox, oy - 2.54)))
    out.append(prop("Footprint", comp.get("footprint", ""), (ox, oy), True))
    out.append(prop("Datasheet", "~", (ox, oy), True))
    out.append(prop("Description", comp.get("description", ""), (ox, oy), True))
    for pin in comp["pin_defs"]:
        out.append(f'\t\t(pin "{pin["number"]}"\n\t\t\t(uuid "{uid()}")\n\t\t)\n')
    out.append('\t\t(instances\n')
    out.append(f'\t\t\t(project "{PROJECT}"\n')
    out.append(f'\t\t\t\t(path "/{ROOT_UUID}"\n')
    out.append(f'\t\t\t\t\t(reference "{comp["ref"]}")\n\t\t\t\t\t(unit 1)\n')
    out.append('\t\t\t\t)\n\t\t\t)\n\t\t)\n')
    out.append("\t)\n")
    return "".join(out)

def transform(pin, origin, orientation=0):
    px, py = pin["x"], pin["y"]
    angle = orientation % 360
    if angle == 90:
        rx, ry = -py, px
    elif angle == 180:
        rx, ry = -px, -py
    elif angle == 270:
        rx, ry = py, -px
    else:
        rx, ry = px, py
    return (origin[0] + rx, origin[1] - ry)

def outward(pin, orientation=0):
    a = (pin["angle"] + orientation) % 360
    if a == 0:
        return (-1.0, 0.0)
    if a == 180:
        return (1.0, 0.0)
    if a == 90:
        return (0.0, 1.0)
    if a == 270:
        return (0.0, -1.0)
    return (1.0, 0.0)
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

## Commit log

2026-09-12 Initial ESP32-C3 radar PCB design and manufacturing release
    [BOM_RX.csv, BOM_TX.csv, BOM_common.csv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]
2026-09-12 Add Gerber and drill archives
2026-09-12 Add combined procurement BOM for TX and RX
    [BOM_BOTH.csv]
2026-09-12 Fix combined BOM format for LCSC upload
    [BOM_BOTH.csv]
2026-09-12 Add LCSC part numbers to combined BOM
    [BOM_BOTH.csv]
2026-09-12 Add LCSC C numbers and template-compatible BOM
    [BOM_BOTH_LCSC.csv]
2026-09-12 Add SolidWorks enclosures for TX and RX
    [RX_Base.SLDPRT, RX_Base.STEP, RX_Cover.SLDPRT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]
2026-09-12 Add validated 3D print STL files and print plates
    [RX_Base.stl, RX_Cover.stl, RX_PrintPlate.stl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]
2026-09-13 Correct enclosure fastening hardware guidance
2026-09-13 Add interactive HTML BOM for TX and RX
2026-09-13 Add LCSC part numbers to PCB metadata and iBOM
    [DormRadar_RX.kicad_pcb, DormRadar_TX.kicad_pcb]
2026-09-25 Add ESP32-C3 firmware and LD2450 detection
